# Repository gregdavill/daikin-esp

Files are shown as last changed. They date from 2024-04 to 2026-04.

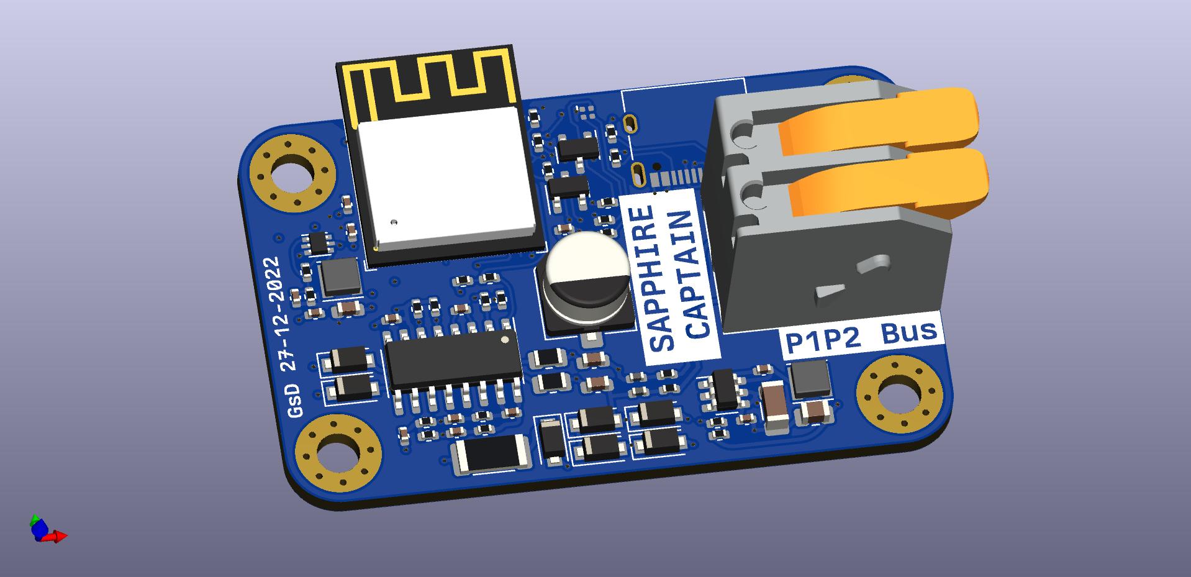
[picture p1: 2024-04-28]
pcb/sapphire-captain/sapphire-captain.jpg

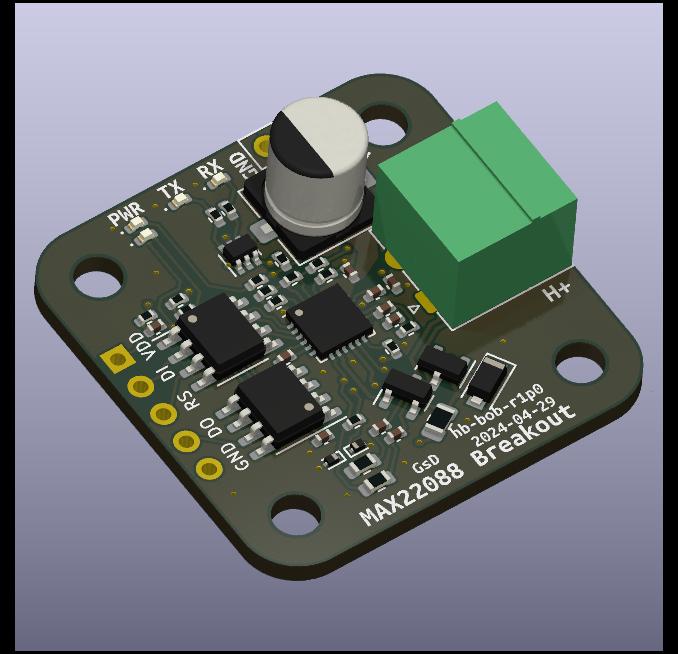
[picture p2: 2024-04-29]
pcb/hb-bob/hb-bob-r1p0.jpg

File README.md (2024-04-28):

# Daikin-ESP

Wireless A/C Controller, an ESP32-C3 based hardware module to connect to a Daikin ducted A/C system and enable WiFi control in Home Assistant.

## Hardware

The PCB repo contains a few different designs:
 - `saphire-captain` : Initial ESP32 + XL1192 board. Power extraction from the bus and transmission didn't work well.
 - `hb-bob-r0.1` : Breakout board designed for the MAX22088 homebus transceiver. This board enabled rx/tx and power from the P1P2 bus.
 - `esp-daikin-r1.0` : Basic ESP32-C3 board with DCDC, dosigned to attach directly to the hb-bob board.

## Firmware

The current firmware targets the `esp-daikin` + `hb-bob` PCB combo. Initial flashing is done with a serial connection to the ESP32-C3. Once flashed OTA updates are supported.
The firmware makes use of esphome to provide the WiFi and Home Assistant code base. A simple C++ component is used to handle the low level encoding, and protocol level decoding.

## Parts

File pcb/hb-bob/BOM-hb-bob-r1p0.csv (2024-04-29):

Comment | Designator | Footprint | LCSC
1K | R13 | R_0402_1005Metric | C11702
1R | R14 | R_0805_2012Metric | C131397
4.7R | R15,R16 | R_0603_1608Metric | C137705
5.6V | D7,D8 | D_SOD-923 | C151980
0.1uF | C1,C2,C3,C5,C8 | C_0402_1005Metric | C1525
10uF | C10,C11,C6 | C_0402_1005Metric | C15525
GREEN | D1,D2,D3,D5 | LED_0402_1005Metric | C165980
180k | R7 | R_0402_1005Metric | C25760
20K | R1,R10,R12,R17,R18,R2,R5,R6 | R_0402_1005Metric | C25765
27K | R8 | R_0402_1005Metric | C25771
4.3K | R9 | R_0402_1005Metric | C25899
82R | R11 | R_0402_1005Metric | C2909389
220uF | C4 | CP_Elec_6.3x7.7 | C2918361
74LVC2G14DW-7 | U3 | SOT-363_SC-70-6 | C362110
62k | R3 | R_0402_1005Metric | C37825
CA-IS3720 | U1,U2 | SOIC-8_3.9x4.9mm_P1.27mm | C428882
MAX22088 | U4 | QFN-24-1EP_4x4mm_P0.5mm_EP2.6x2.6mm | C5258925
1uF | C7,C9 | C_0402_1005Metric | C52923
0R | R4 | R_0402_1005Metric | C60485
Terminal Block 2P | J3 | PhoenixContact_MC_1,5_2-G-3.81_1x02_P3.81mm_Horizontal | C8387
24V | D6 | D_SOD-123F | C908212
BAT54S | D4,D9 | SOT-23 | C916425
PH_01x05 | J1 | PinHeader_1x05_P2.54mm_Vertical
PinHeader 1x02 | J2 | PinHeader_1x02_P2.54mm_Vertical

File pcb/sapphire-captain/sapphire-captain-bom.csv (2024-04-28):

Item | Qty | Reference(s) | Value | LibPart | Footprint | Datasheet | MFG | Mfg | PN | PN-alt0 | Tol | lcsc
21 | 7 | C2, C4, C13, C16, C18, C19, C20 | 0.1uF | Device:C | Capacitor_SMD:C_0402_1005Metric | ~ | Samsung Electro-Mechanics | Yageo | CL05B104KO5NNNC
3 | 1 | C3 | 22uF | Device:C | Capacitor_SMD:C_1206_3216Metric | ~ | Samsung Electro-Mechanics | Yageo | CL31A226KAHNNNE
9 | 3 | C5, C6, C11 | 10uF | Device:C | Capacitor_SMD:C_0603_1608Metric | ~ | Samsung Electro-Mechanics | Yageo | CL10A106KP8NNNC
9 | 3 | C7, C8, C9 | 22nF | Device:C | Capacitor_SMD:C_0402_1005Metric | ~ | Samsung Electro-Mechanics | Yageo | CL05B223KB5VPNC
3 | 1 | C10 | 6.8pF | Device:C | Capacitor_SMD:C_0402_1005Metric | ~ | Samsung Electro-Mechanics | Yageo | CC0402CRNPO9BN6R8
3 | 1 | C12 | 470p | Device:C | Capacitor_SMD:C_0402_1005Metric | ~ | Samsung Electro-Mechanics |  | CL05B471KB5NNNC
3 | 1 | C14 | 1uF | Device:C | Capacitor_SMD:C_0402_1005Metric | ~ | Samsung Electro-Mechanics | Yageo | CL05X105KA5NQNC
3 | 1 | C15 | 47uF | Device:C_Polarized_US | Capacitor_SMD:CP_Elec_6.3x4.5 | ~ | DMBJ |  | RVT1V470M0605 | ROQANG |  | C72522
3 | 1 | C17 | 22uF | Device:C | Capacitor_SMD:C_0805_2012Metric | ~ | Samsung Electro-Mechanics |  | CL21A226MAYNNNE
3 | 1 | D1 | 16V | Device:D_TVS_Filled | Diode_SMD:D_SOD-123F | ~ |  |  | BZT52H-C16,115
12 | 4 | D2, D3, D4, D5 | D_Filled | Device:D_Filled | Diode_SMD:D_SOD-123F | ~ | Shandong Jingdao Microelectronics |  | 1N5819W
6 | 2 | D6, D7 | 5.6V | Device:D_TVS_Filled | Diode_SMD:D_SOD-123F | ~ |  |  | BZT52H-B5V6,115
3 | 1 | D8 | LED_ARGB | Device:LED_ARGB | lib:0404LED_RGB | ~
6 | 2 | F1, F2 | 100mA | Device:Fuse_Small | Fuse:Fuse_0402_1005Metric | ~ | Shenzhen JDT Fuse |  | JFC0402-0250FS
6 | 2 | FB1, FB2 | 220R | Device:FerriteBead_Small | Inductor_SMD:L_0402_1005Metric | ~ | Chilisin Elec |  | PBY100505T-101Y-N
3 | 1 | J1 | Conn_01x02 | Connector_Generic:Conn_01x02 | TerminalBlock_WAGO:TerminalBlock_WAGO_236-102_1x02_P5.00mm_45Degree | ~ | WAGO Corporation |  | 2604-1102
3 | 1 | J2 | USB_C_Receptacle_USB2.0 | Connector:USB_C_Receptacle_USB2.0 | Connector_USB:USB_C_Receptacle_XKB_U262-16XN-4BVC11 | https://www.usb.org/sites/default/files/documents/usb_type-c.zip
3 | 1 | J3 | JTAG/SW Interface | Connector_Generic:Conn_02x05_Odd_Even | Connector_PinHeader_1.27mm:PinHeader_2x05_P1.27mm_Vertical_SMD | ~
3 | 1 | L1 | 2.2uH | Device:L_Small | Inductor_SMD:L_Taiyo-Yuden_NR-30xx | ~ |  | MINGSTAR | UT252010N-2R2M
3 | 1 | L2 | 10uH | Device:L_Small | Inductor_SMD:L_Taiyo-Yuden_NR-30xx | ~ | YJYCOIN |  | YNR3015-100M |  |  | C340363
6 | 2 | Q1, Q2 | 2N7002 | Device:Q_NMOS_GSD | Package_TO_SOT_SMD:SOT-23 | ~ | Jiangsu Changjing Electronics Technology Co., Ltd. |  | 2N7002
3 | 1 | R1 | 30R | Device:R | Resistor_SMD:R_2010_5025Metric | ~ | YAGEO |  | RC2010JK-0730RL
6 | 2 | R2, R3 | 1.5k | Device:R | Resistor_SMD:R_0402_1005Metric | ~ | YAGEO |  | RC0402FR-071K5L
6 | 2 | R4, R17 | 22k | Device:R | Resistor_SMD:R_0402_1005Metric | ~ | YAGEO | Yageo | RC0402FR-0722KL
3 | 1 | R5 | 115k | Device:R | Resistor_SMD:R_0402_1005Metric | ~ | YAGEO | Yageo | RC0402FR-07115KL |  | 1%
3 | 1 | R6 | 25.5k | Device:R | Resistor_SMD:R_0402_1005Metric | ~ | YAGEO | Yageo | RC0402FR-0725K5L
3 | 1 | R7 | 100k | Device:R | Resistor_SMD:R_0402_1005Metric | ~ | YAGEO | Yageo | RC0402FR-07100KL |  | 1%
6 | 2 | R8, R9 | 75k | Device:R | Resistor_SMD:R_0402_1005Metric | ~ | YAGEO |  | RC0402FR-0775KL
6 | 2 | R10, R11 | 1R | Device:R | Resistor_SMD:R_0805_2012Metric | ~ | YAGEO |  | RC0805FR-071RL
3 | 1 | R12 | DNP | Device:R | Resistor_SMD:R_0402_1005Metric | ~ | YAGEO
3 | 1 | R13 | 0R | Device:R | Resistor_SMD:R_0402_1005Metric | ~ | YAGEO |  | RC0402FR-070RL
15 | 5 | R14, R15, R16, R18, R21 | 10k | Device:R | Resistor_SMD:R_0402_1005Metric | ~ | YAGEO |  | RC0402FR-0710KL
3 | 1 | R19 | 4.7k | Device:R | Resistor_SMD:R_0402_1005Metric | ~ | YAGEO |  | RC0402FR-074K7L
9 | 3 | R20, R22, R23 | 470R | Device:R | Resistor_SMD:R_0402_1005Metric | ~ | YAGEO |  | RC0402FR-07470RL
6 | 2 | R24, R25 | 5.1K | Device:R | Resistor_SMD:R_0402_1005Metric | ~ | YAGEO |  | RC0402FR-075K1L
3 | 1 | SW1 | SW_DIP_x01 | Switch:SW_DIP_x01 | Button_Switch_SMD:SW_SPST_PTS810 | ~ | C&K |  | PTS810SJK250SMTRLFS
3 | 1 | U1 | MT2492 | lib:MT2492 | Package_TO_SOT_SMD:SOT-23-6 | https://datasheet.lcsc.com/lcsc/1810262207_XI-AN-Aerosemi-Tech-MT2492_C89358.pdf | XI'AN Aerosemi Tech |  | MT2492
3 | 1 | U2 | TLV62569DRL | Regulator_Switching:TLV62569DRL | Package_TO_SOT_SMD:SOT-666 | http://www.ti.com/lit/ds/symlink/tlv62569.pdf | Texas Instruments | Texas Instruments | TLV62569DRLR
3 | 1 | U3 | XL1192 | sapphire-captain:XL1192 | Package_SO:SO-16_3.9x9.9mm_P1.27mm |  | XLSEMI |  | XL1192S
3 | 1 | U4 | ESP32-C3-MINI-1 | Espressif:ESP32-C3-MINI-1 | Espressif:ESP32-C3-MINI-1 | https://www.espressif.com/sites/default/files/documentation/esp32-c3-mini-1_datasheet_en.pdf

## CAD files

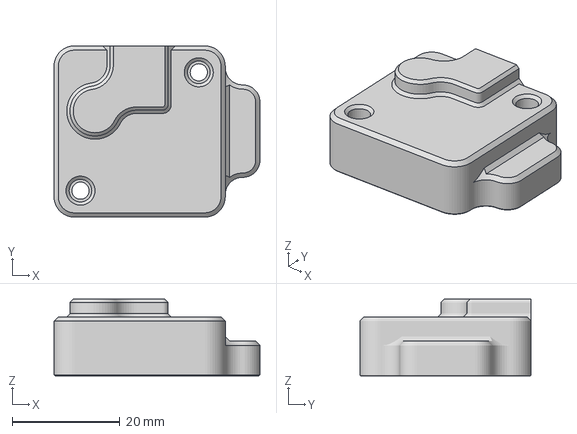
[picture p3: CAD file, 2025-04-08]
mech/top_1.0.0.3mf
38.3 x 31.9 x 14.3 mm

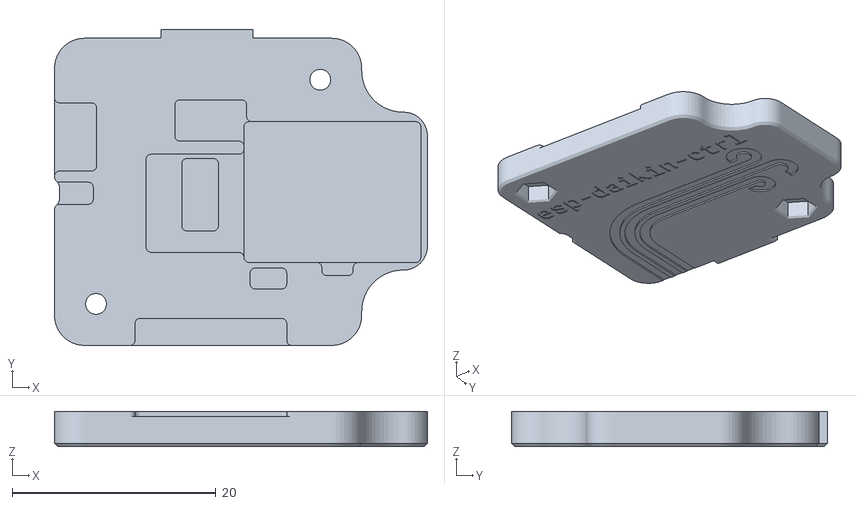
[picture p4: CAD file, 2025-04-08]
mech/bot_1.1.0.stl
36.6 x 31.0 x 3.44

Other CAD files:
mech/top_1.1.0.stl
mech/bot_1.0.0.3mf

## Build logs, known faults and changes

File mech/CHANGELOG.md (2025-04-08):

# Change Log
Mechanical designs are developed in Autodesk Fusion. Exports of that design are used for 3d prints and saved in this repo.

## [1.1.0]
2025-02-13: Updated design. Printed with SLS Nylon.

### Fixes
 - Shrink hole sizes to better support fasteners

### Files
 - top_1.1.0.stl
 - bot_1.1.0.stl

## [1.0.0]
2024-03-08: Initial design. Printed with SLS Nylon.

### Files
 - top_1.0.0.3mf
 - bot_1.0.0.3mf

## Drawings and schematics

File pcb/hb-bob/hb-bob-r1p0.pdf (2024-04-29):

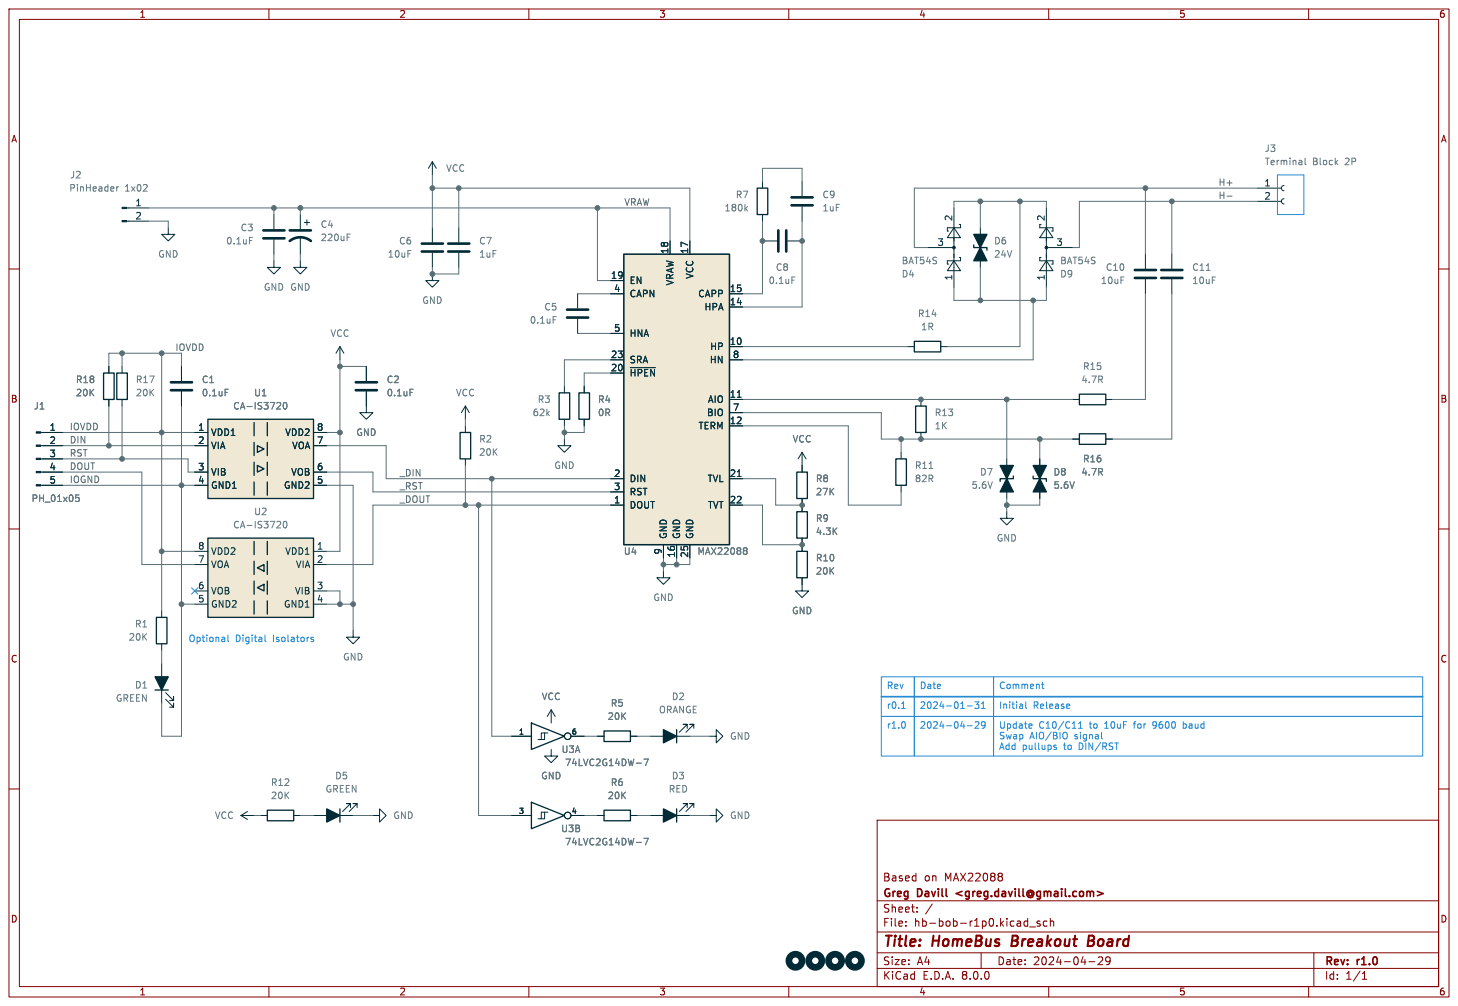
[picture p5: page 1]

9 U1 CA-IS3720 VDD1 1 VIA 2 VIB 3 GND1 4 GND2 5 VOB 6 VOA 7 VDD2 8 C1

Id: 1/1 Title: HomeBus Breakout Board

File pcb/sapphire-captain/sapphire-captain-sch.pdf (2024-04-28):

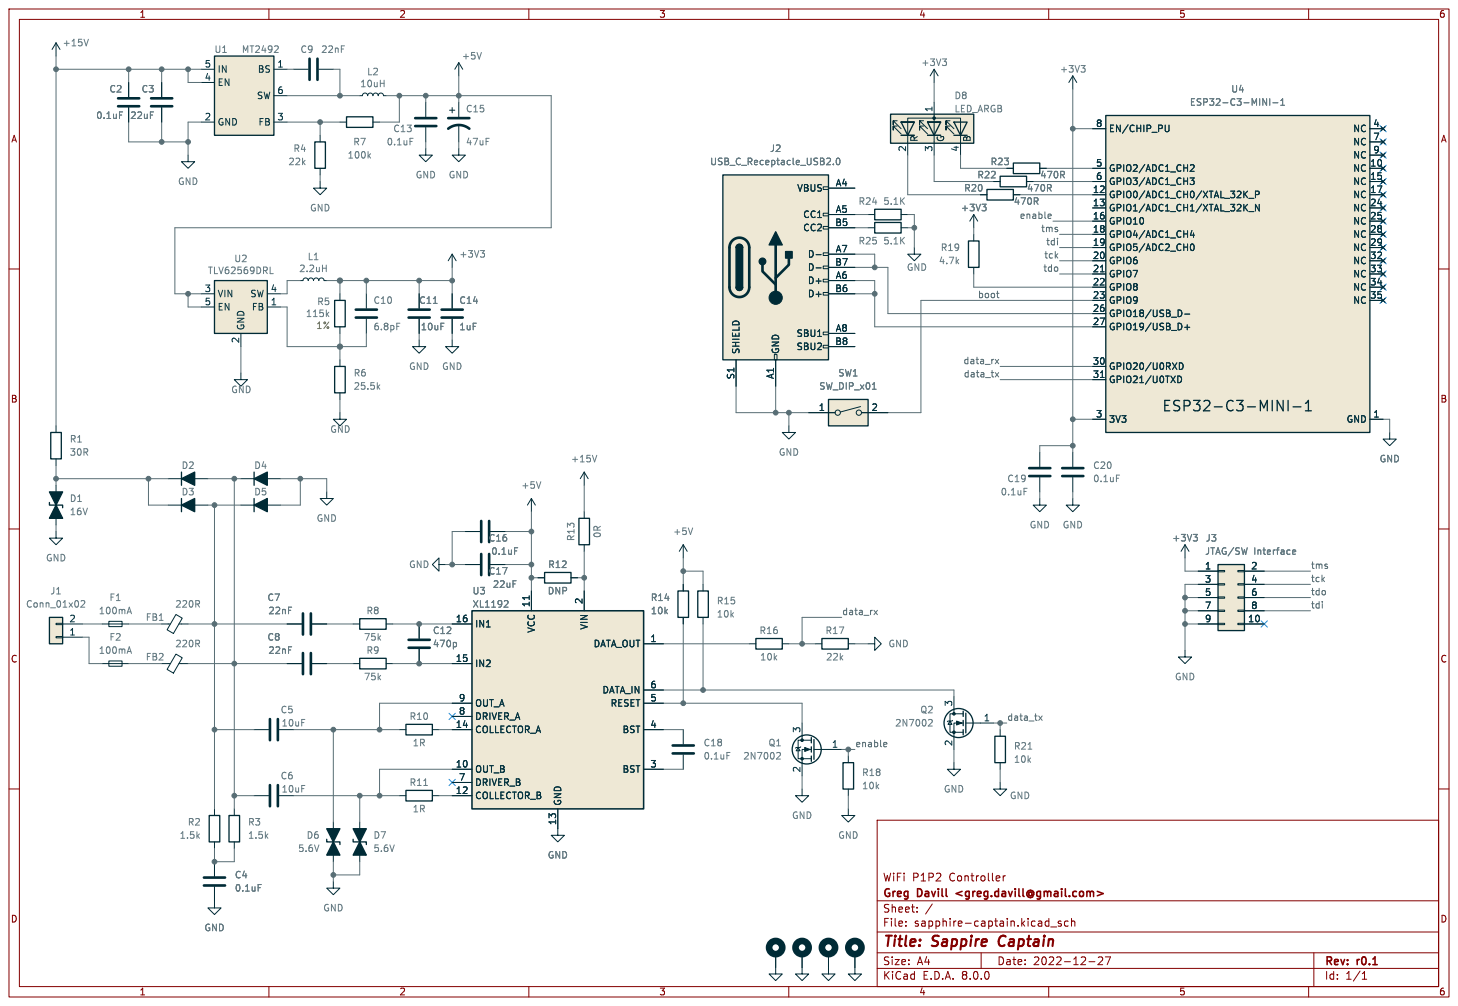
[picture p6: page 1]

2 BST 3 BST 4 RESET 5 DATA_IN 6 DRIVER_B 7 DRIVER_A 8 OUT_A 9 GND

Id: 1/1 Title: Sappire Captain

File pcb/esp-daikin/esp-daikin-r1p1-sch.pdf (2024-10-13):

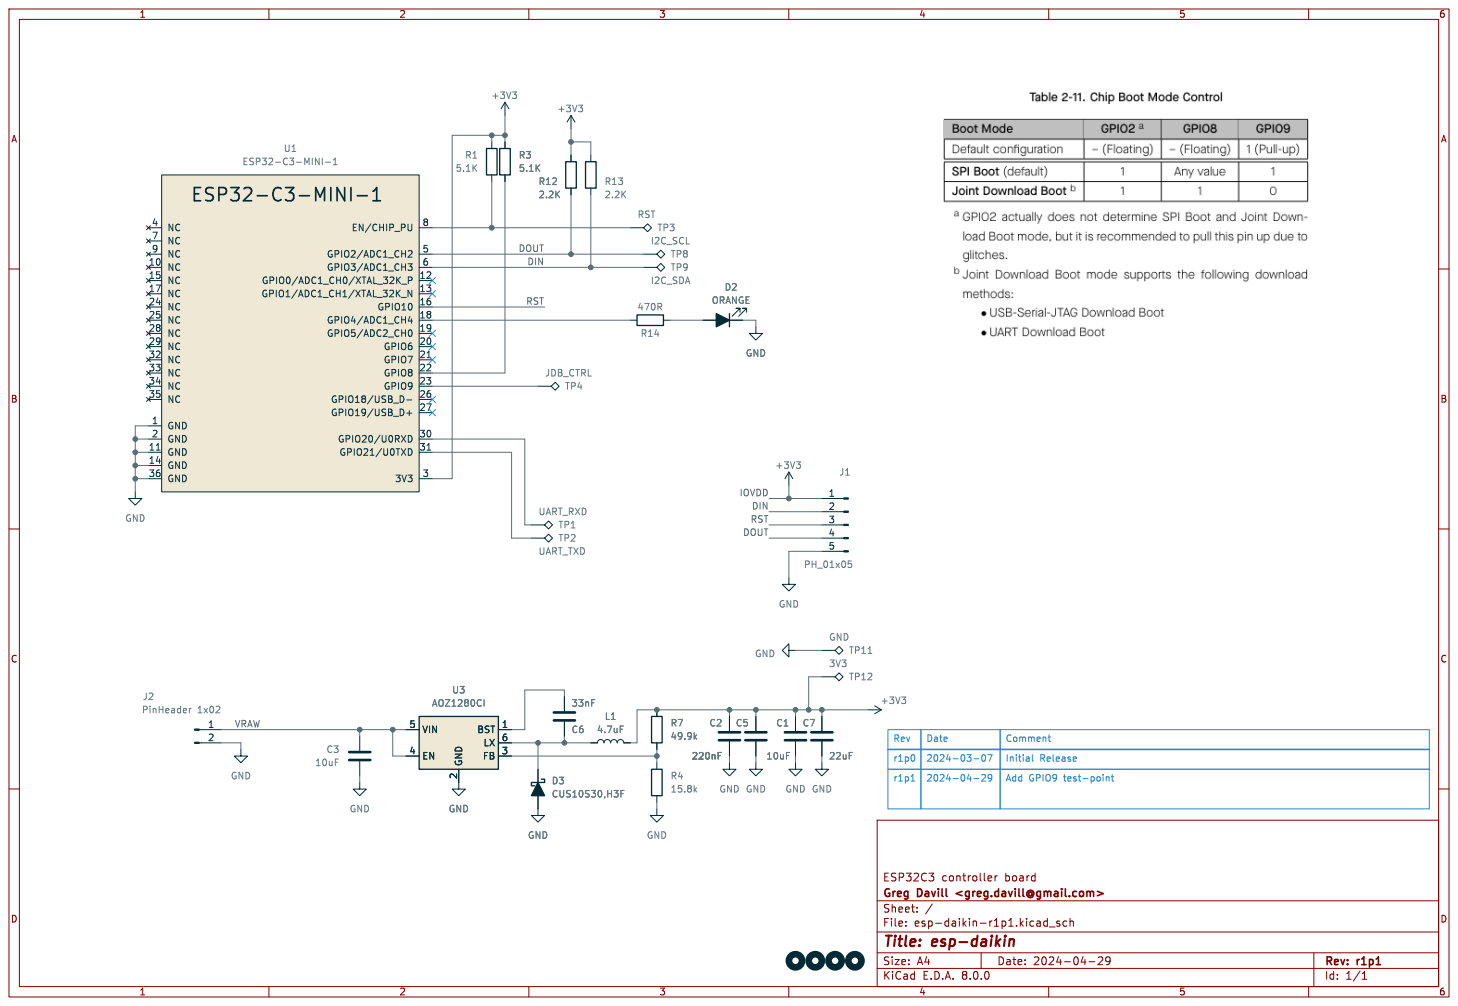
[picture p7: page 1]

Id: 1/1 Title: esp-daikin

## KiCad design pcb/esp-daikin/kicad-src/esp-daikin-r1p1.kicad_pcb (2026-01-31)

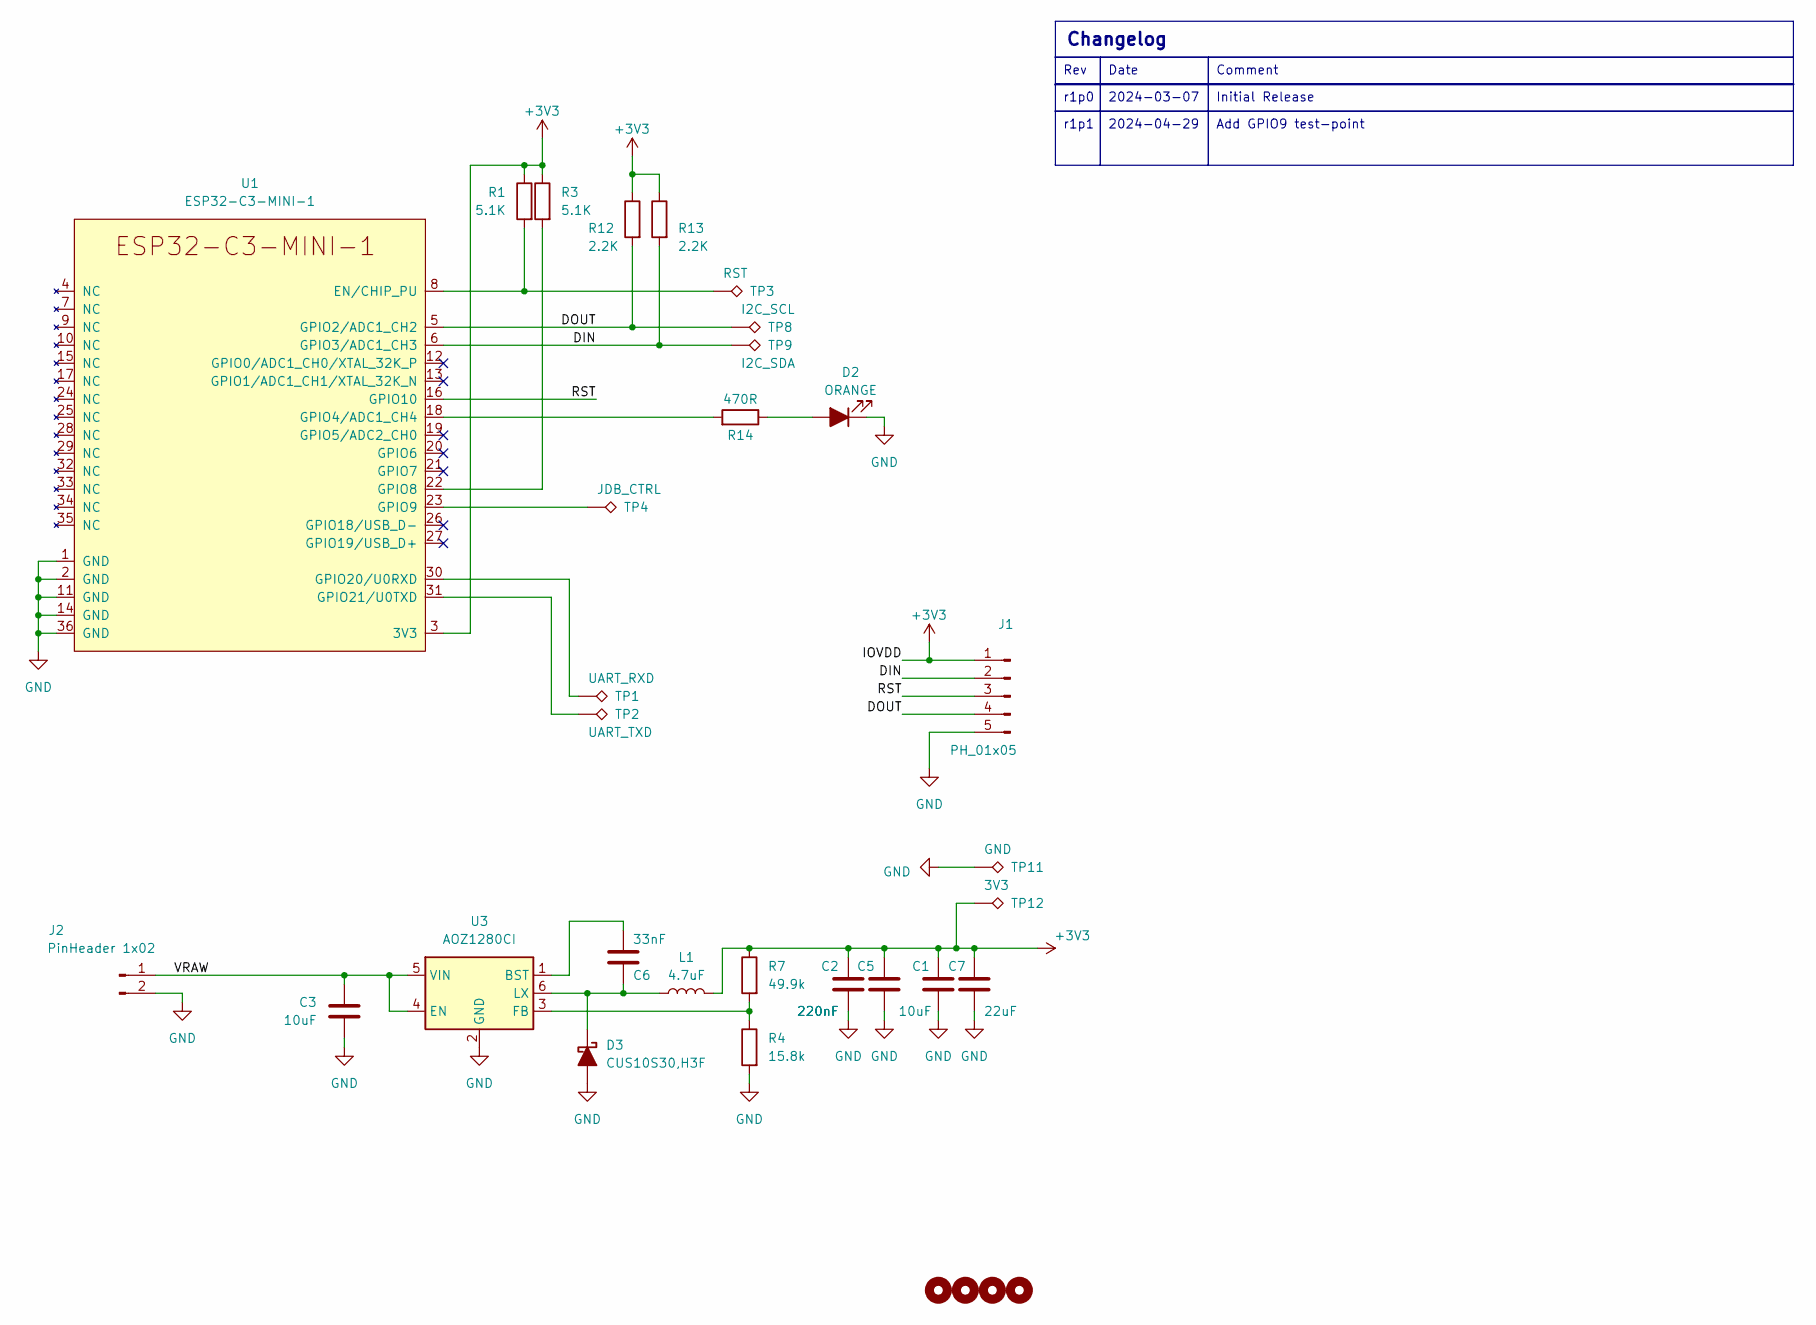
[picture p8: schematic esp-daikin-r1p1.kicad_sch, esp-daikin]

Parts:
C1, C3: 10uF; C_0603_1608Metric; LCSC C96446
C2, C5: 220nF; C_0402_1005Metric; LCSC C16772
C6: 33nF; C_0402_1005Metric; LCSC C106862
C7: 22uF; C_0603_1608Metric; LCSC C59461
D2: ORANGE; LED_0402_1005Metric; LCSC C965791
D3: CUS10S30,H3F; D_SOD-523; LCSC C8523
H1, H2, H3, H4: MountingHole; MountingHole_3.2mm_M3_DIN965
J1: PH_01x05; PinHeader_1x05_P2.54mm_Vertical
J2: PinHeader 1x02; PinHeader_1x02_P2.54mm_Vertical
L1: 4.7uF; L_0805_2012Metric; LCSC C63166
R1, R3: 5.1K; R_0402_1005Metric; LCSC C25905
R4: 15.8k; R_0402_1005Metric; LCSC C26956
R7: 49.9k; R_0402_1005Metric; LCSC C25897
R12, R13: 2.2K; R_0402_1005Metric; LCSC C25879
R14: 470R; R_0402_1005Metric; LCSC C25117
TP1: UART_RXD; TestPoint_Pad_D1.0mm
TP2: UART_TXD; TestPoint_Pad_D1.0mm
TP3: RST; TestPoint_Pad_D1.0mm
TP4: JDB_CTRL; TestPoint_Pad_D1.0mm
TP8: I2C_SCL; TestPoint_Pad_D1.0mm
TP9: I2C_SDA; TestPoint_Pad_D1.0mm
TP11: GND; TestPoint_Pad_D1.0mm
TP12: 3V3; TestPoint_Pad_D1.0mm
U1: ESP32-C3-MINI-1; LCSC C2934569
U3: AOZ1280CI; SOT-23-6; LCSC C41240

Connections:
+3V3: C1.1, C2.1, C5.1, C7.1, J1.1, L1.2, R1.1, R3.1, R7.1, R12.1, R13.1, TP12.1, U1.3 (3V3)
/DIN: J1.2, R13.2, TP9.1, U1.6 (GPIO3/ADC1_CH3)
/DOUT: J1.4, R12.2, TP8.1, U1.5 (GPIO2/ADC1_CH2)
/RST: J1.3, U1.16 (GPIO10)
/VRAW: C3.1, J2.1, U3.4 (EN), U3.5 (VIN)
GND: C1.2, C2.2, C3.2, C5.2, C7.2, D2.1 (K), D3.2 (A), J1.5, J2.2, R4.2, TP11.1, U1.1 (GND), U1.2 (GND), U1.11 (GND), U1.14 (GND), U1.36 (GND), U1.37 (GND), U1.38 (GND), U1.39 (GND), U1.40 (GND), U1.41 (GND), U1.42 (GND), U1.43 (GND), U1.44 (GND), U1.45 (GND), U1.46 (GND), U1.47 (GND), U1.48 (GND), U1.49 (GND), U1.50 (GND), U1.51 (GND), U1.52 (GND), U1.53 (GND), U3.2 (GND)
unnamed: D2.2 (A), R14.1
unnamed: C6.1, D3.1 (K), L1.1, U3.6 (LX)
unnamed: R1.2, TP3.1, U1.8 (EN/CHIP_PU)
unnamed: R14.2, U1.18 (GPIO4/ADC1_CH4)
unnamed: R3.2, U1.22 (GPIO8)
unnamed: TP4.1, U1.23 (GPIO9)
unnamed: TP1.1, U1.30 (GPIO20/U0RXD)
unnamed: TP2.1, U1.31 (GPIO21/U0TXD)
unnamed: C6.2, U3.1 (BST)
unnamed: R4.1, R7.2, U3.3 (FB)

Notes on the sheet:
Add GPIO9 test-point
Date
r1p0
Changelog
Rev
Comment
2024-03-07
2024-04-29
Initial Release
r1p1

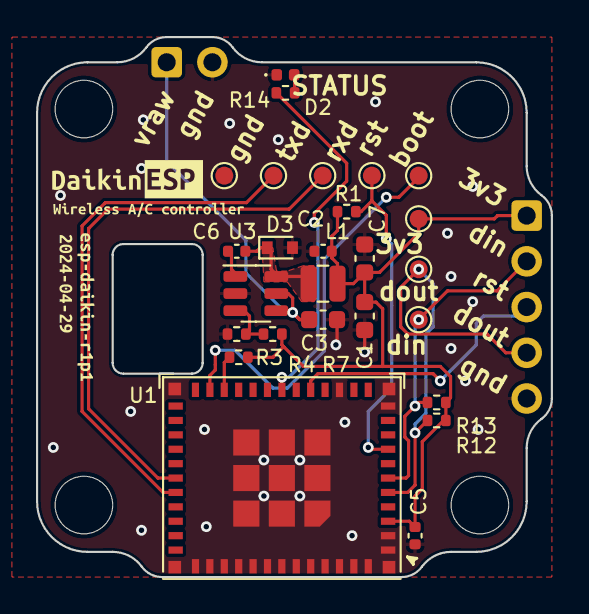
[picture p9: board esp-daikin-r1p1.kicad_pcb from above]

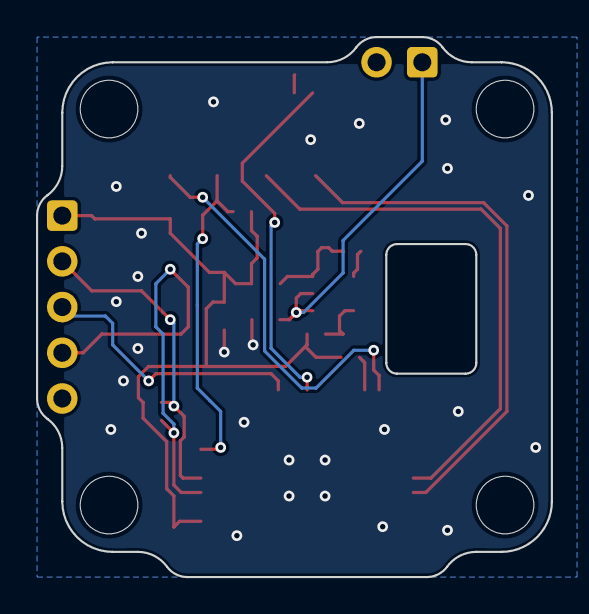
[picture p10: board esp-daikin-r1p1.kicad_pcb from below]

Board: 2 copper layers, 28.6 x 30.0 mm, 37 parts (6 on the bottom side), 16 nets.

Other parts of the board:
kibuzzard-65E1B0DF: G***; kibuzzard-65E1B0DF
kibuzzard-65E1B071: G***; kibuzzard-65E1B071
kibuzzard-65E1B080: G***; kibuzzard-65E1B080
kibuzzard-663027A7: G***; kibuzzard-663027A7
kibuzzard-663027CC: G***; kibuzzard-663027CC

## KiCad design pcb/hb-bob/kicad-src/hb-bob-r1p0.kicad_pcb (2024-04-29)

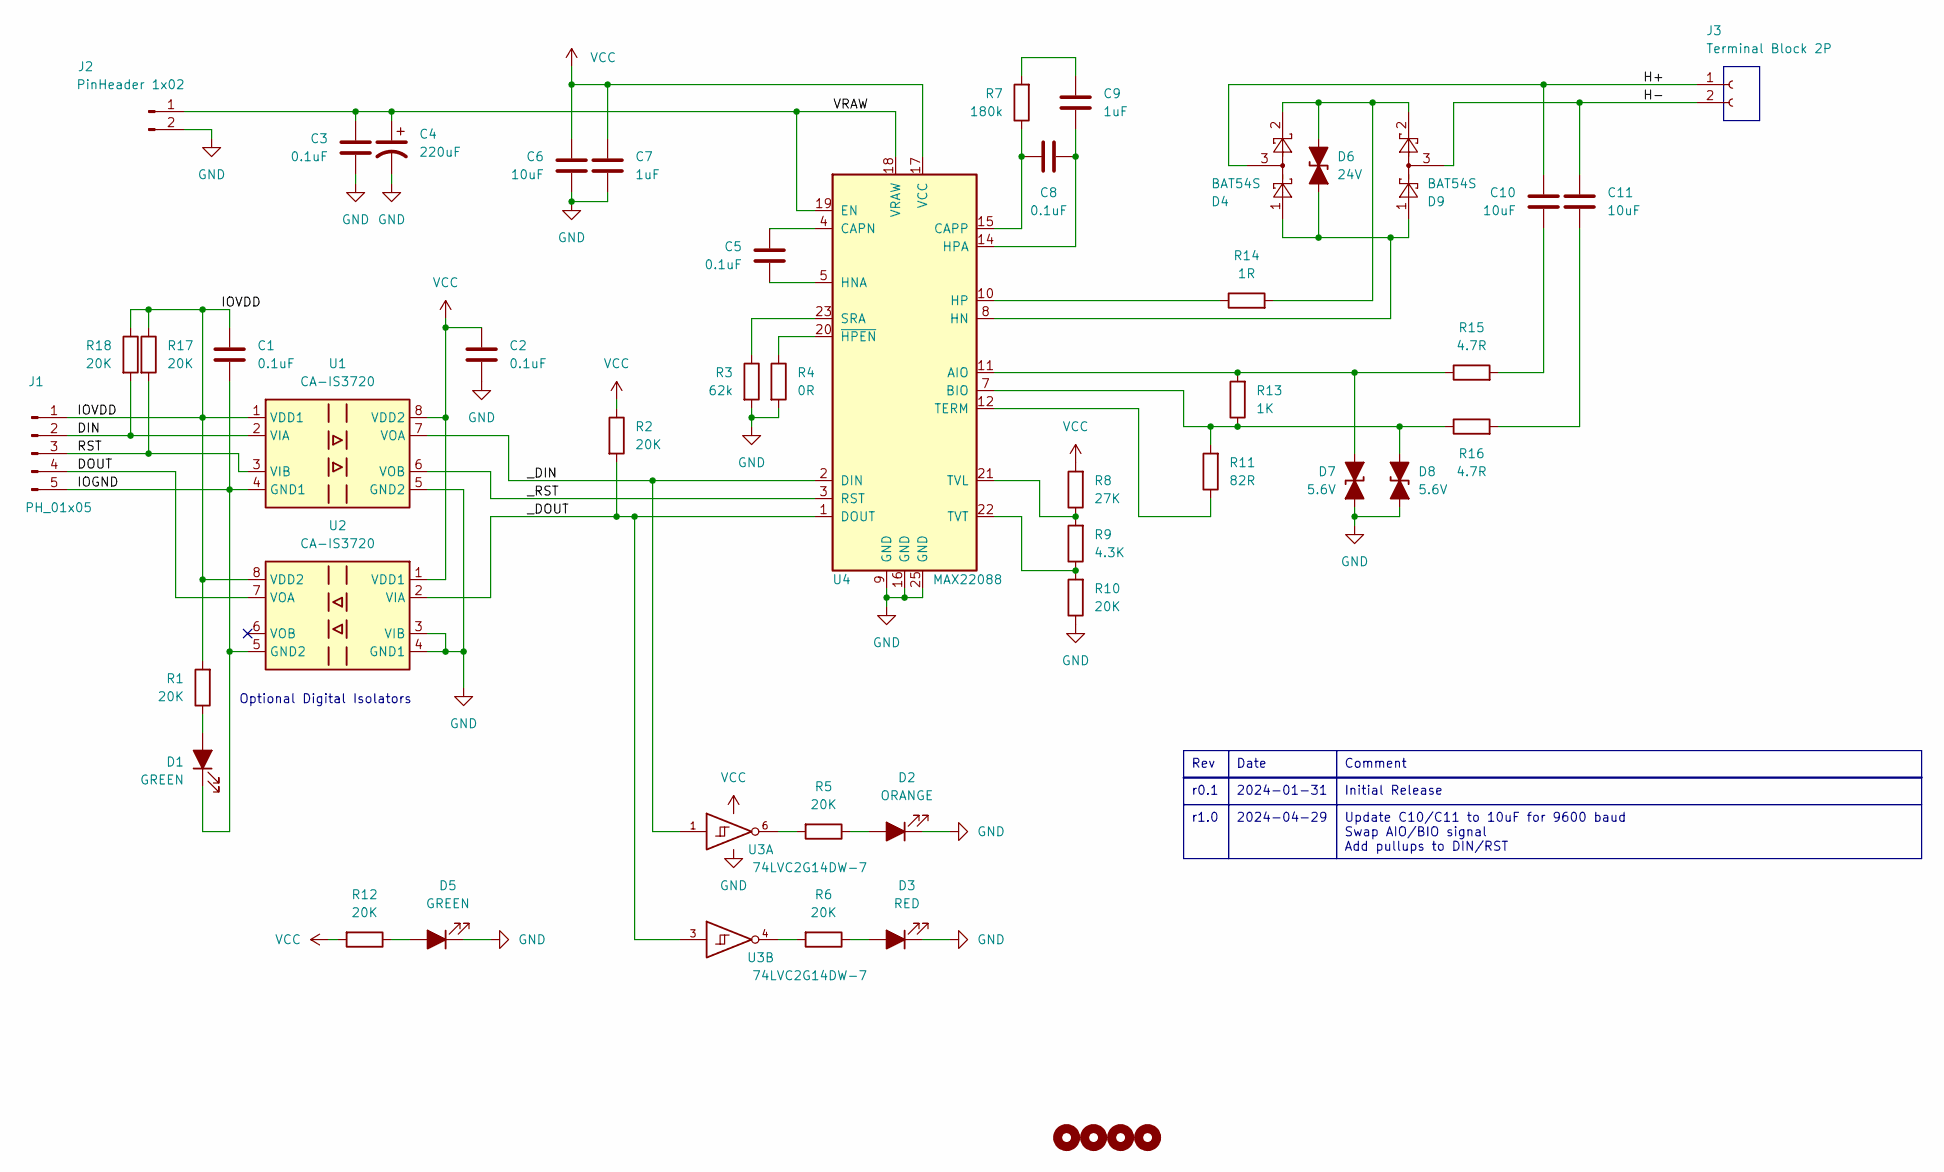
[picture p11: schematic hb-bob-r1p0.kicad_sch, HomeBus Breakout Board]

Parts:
C1, C2, C3, C5, C8: 0.1uF; C_0402_1005Metric; LCSC C1525
C4: 220uF; CP_Elec_6.3x7.7; LCSC C2918361
C6, C10, C11: 10uF; C_0402_1005Metric; LCSC C15525
C7, C9: 1uF; C_0402_1005Metric; LCSC C52923
D1, D5: GREEN; LED_0402_1005Metric; LCSC C165980
D2: ORANGE; LED_0402_1005Metric; LCSC C165980
D3: RED; LED_0402_1005Metric; LCSC C165980
D4, D9: BAT54S; SOT-23; LCSC C916425
D6: 24V; D_SOD-123F; LCSC C908212
D7, D8: 5.6V; D_SOD-923; LCSC C151980
H1, H2, H3, H4: MountingHole; MountingHole_3.2mm_M3_DIN965
J1: PH_01x05; PinHeader_1x05_P2.54mm_Vertical
J2: PinHeader 1x02; PinHeader_1x02_P2.54mm_Vertical
J3: Terminal Block 2P; PhoenixContact_MC_1,5_2-G-3.81_1x02_P3.81mm_Horizontal; LCSC C8387
R1, R2, R5, R6, R10, R12, R17, R18: 20K; R_0402_1005Metric; LCSC C25765
R3: 62k; R_0402_1005Metric; LCSC C37825
R4: 0R; R_0402_1005Metric; LCSC C60485
R7: 180k; R_0402_1005Metric; LCSC C25760
R8: 27K; R_0402_1005Metric; LCSC C25771
R9: 4.3K; R_0402_1005Metric; LCSC C25899
R11: 82R; R_0402_1005Metric; LCSC C2909389
R13: 1K; R_0402_1005Metric; LCSC C11702
R14: 1R; R_0805_2012Metric; LCSC C131397
R15, R16: 4.7R; R_0603_1608Metric; LCSC C137705
U1, U2: CA-IS3720; SOIC-8_3.9x4.9mm_P1.27mm; LCSC C428882
U3: 74LVC2G14DW-7; SOT-363_SC-70-6; LCSC C362110
U4: MAX22088; QFN-24-1EP_4x4mm_P0.5mm_EP2.6x2.6mm; LCSC C5258925

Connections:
/DIN: J1.2, R18.2, U1.2 (VIA)
/DOUT: J1.4, U2.7 (VOA)
/H+: C10.2, D4.3, J3.1
/H-: C11.2, D9.3, J3.2
/IOGND: C1.2, D1.1 (K), J1.5, U1.4 (GND1), U2.5 (GND2)
/IOVDD: C1.1, J1.1, R1.2, R17.1, R18.1, U1.1 (VDD1), U2.8 (VDD2)
/RST: J1.3, R17.2, U1.3 (VIB)
/VRAW: C3.1, C4.1, J2.1, U4.18 (VRAW), U4.19 (EN)
/_DIN: U1.7 (VOA), U3.1, U4.2 (DIN)
/_DOUT: R2.2, U2.2 (VIA), U3.3, U4.1 (DOUT)
/_RST: U1.6 (VOB), U4.3 (RST)
GND: C2.2, C3.2, C4.2, C6.2, C7.2, D2.1 (K), D3.1 (K), D5.1 (K), D7.2 (A2), D8.2 (A2), J2.2, R3.2, R4.2, R10.1, U1.5 (GND2), U2.3 (VIB), U2.4 (GND1), U3.2 (GND), U4.9 (GND), U4.16 (GND), U4.25 (GND)
unnamed: C9.1, R7.2
unnamed: C10.1, R15.2
unnamed: C11.1, R16.2
unnamed: D1.2 (A), R1.1
unnamed: D2.2 (A), R5.1
unnamed: D3.2 (A), R6.1
unnamed: D5.2 (A), R12.1
unnamed: D4.1, D6.1 (A1), D9.1, U4.8 (HN)
unnamed: D4.2, D6.2 (A2), D9.2, R14.2
unnamed: D7.1 (A1), R13.2, R15.1, U4.11 (AIO)
unnamed: D8.1 (A1), R11.2, R13.1, R16.1, U4.7 (BIO)
unnamed: R5.2, U3.6
unnamed: R6.2, U3.4
unnamed: C5.1, U4.4 (CAPN)
unnamed: C8.2, R7.1, U4.15 (CAPP)
unnamed: C5.2, U4.5 (HNA)
unnamed: R14.1, U4.10 (HP)
unnamed: C8.1, C9.2, U4.14 (HPA)
unnamed: R3.1, U4.23 (SRA)
unnamed: R11.1, U4.12 (TERM)
unnamed: R8.1, R9.2, U4.21 (TVL)
unnamed: R9.1, R10.2, U4.22 (TVT)
unnamed: R4.1, U4.20 (~HPEN)
VCC: C2.1, C6.1, C7.1, R2.1, R8.2, R12.2, U1.8 (VDD2), U2.1 (VDD1), U3.5 (VCC), U4.17 (VCC)

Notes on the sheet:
r0.1
2024-04-29
Initial Release
Update C10/C11 to 10uF for 9600 baud Swap AIO/BIO signal Add pullups to DIN/RST
Comment
Rev
2024-01-31
Date
r1.0
Optional Digital Isolators

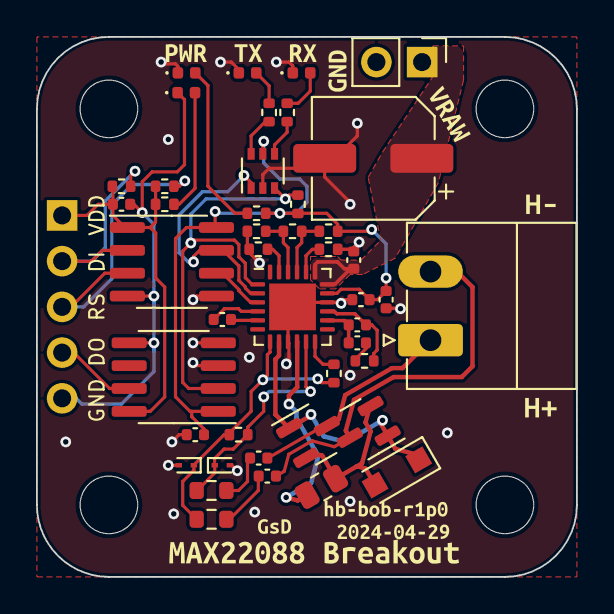
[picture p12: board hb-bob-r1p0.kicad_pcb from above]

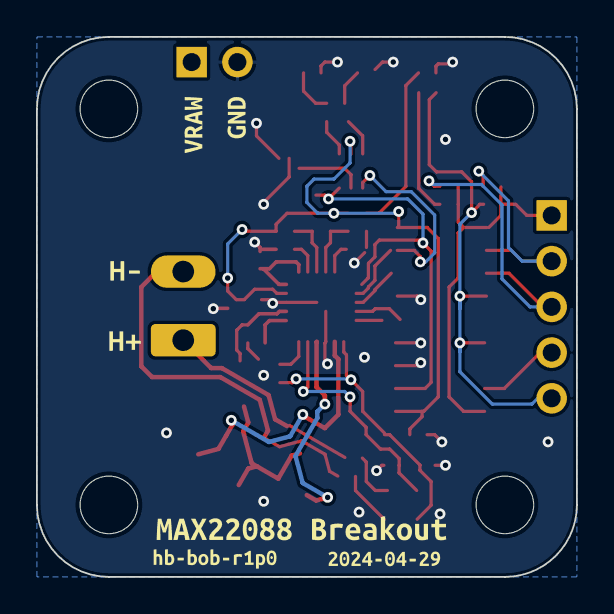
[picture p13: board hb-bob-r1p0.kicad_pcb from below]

Board: 2 copper layers, 30.0 x 30.0 mm, 67 parts (7 on the bottom side), 36 nets.

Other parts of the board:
kibuzzard-65B6C60D, kibuzzard-65B6C60D#2: G***; kibuzzard-65B6C60D
kibuzzard-65B6C61A, kibuzzard-65B6C61A#2: G***; kibuzzard-65B6C61A
kibuzzard-65B9E354: G***; kibuzzard-65B9E354
kibuzzard-65B62A1A, kibuzzard-65B62A1A#2: G***; kibuzzard-65B62A1A
kibuzzard-65B62B19, kibuzzard-65B62B19#2: G***; kibuzzard-65B62B19
kibuzzard-65B62B21, kibuzzard-65B62B21#2: G***; kibuzzard-65B62B21
kibuzzard-65B629C5: G***; kibuzzard-65B629C5
kibuzzard-65B629E6: G***; kibuzzard-65B629E6
kibuzzard-65B629EE: G***; kibuzzard-65B629EE
kibuzzard-662F7DF1: G***; kibuzzard-662F7DF1
kibuzzard-662F7DF9: G***; kibuzzard-662F7DF9
kibuzzard-662F7E09: G***; kibuzzard-662F7E09
kibuzzard-662F7E13: G***; kibuzzard-662F7E13

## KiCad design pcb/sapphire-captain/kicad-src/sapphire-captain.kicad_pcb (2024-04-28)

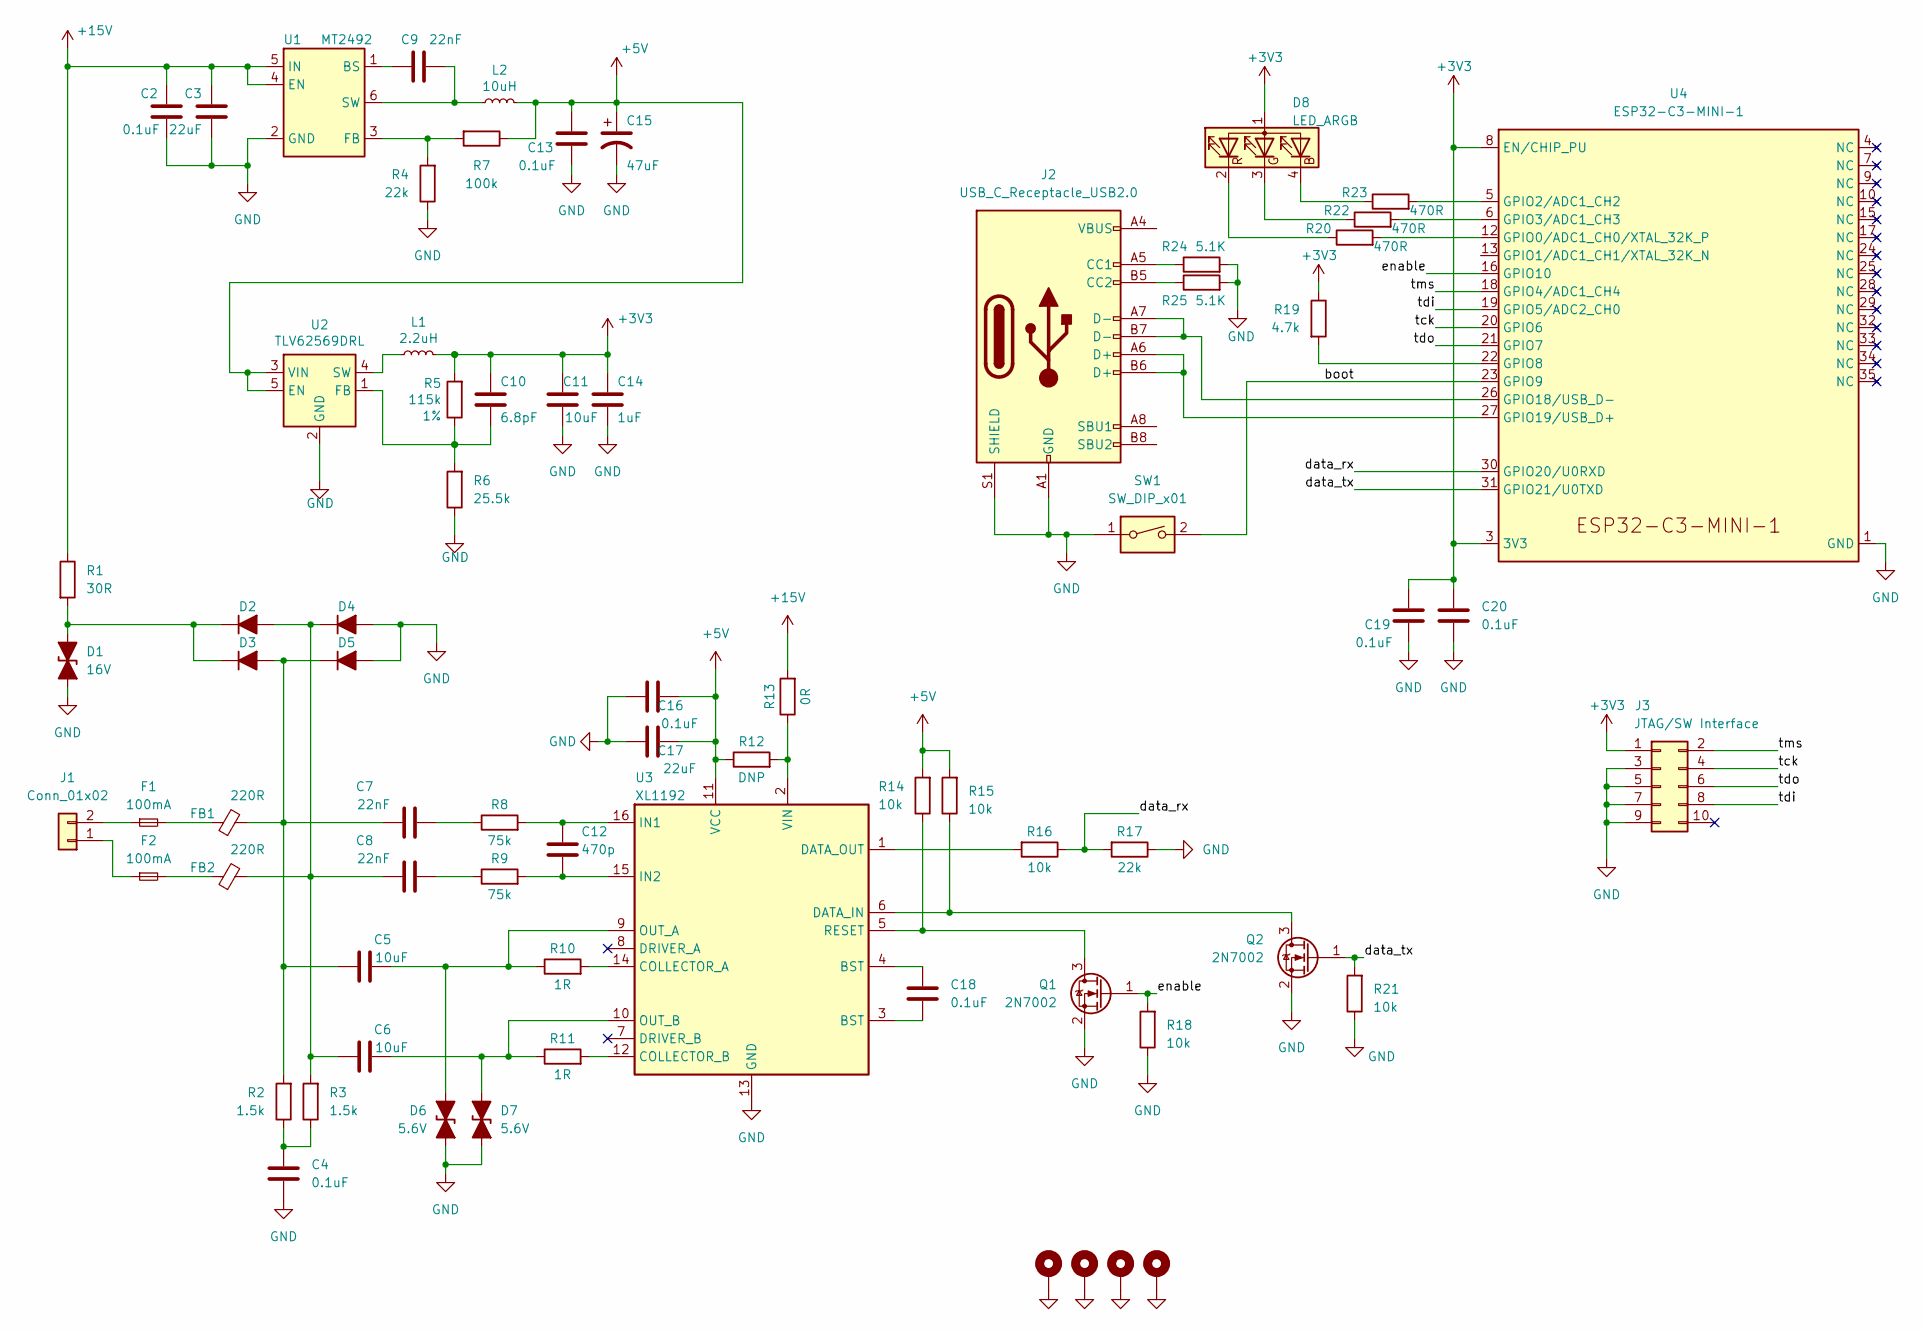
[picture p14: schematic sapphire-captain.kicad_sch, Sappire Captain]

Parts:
C2, C4, C13, C16, C18, C19, C20: 0.1uF; C_0402_1005Metric
C3: 22uF; C_1206_3216Metric
C5, C6, C11: 10uF; C_0603_1608Metric
C7, C8, C9: 22nF; C_0402_1005Metric
C10: 6.8pF; C_0402_1005Metric
C12: 470p; C_0402_1005Metric
C14: 1uF; C_0402_1005Metric
C15: 47uF; CP_Elec_6.3x4.5; lcsc C72522
C17: 22uF; C_0805_2012Metric
D1: 16V; D_SOD-123F
D2, D3, D4, D5: D_Filled; D_SOD-123F
D6, D7: 5.6V; D_SOD-123F
D8: LED_ARGB; 0404LED_RGB
F1, F2: 100mA; Fuse_0402_1005Metric
FB1, FB2: 220R; L_0402_1005Metric
H1, H2, H3, H4: MountingHole_Pad; MountingHole_3.2mm_M3_Pad_Via
J1: Conn_01x02; TerminalBlock_WAGO_236-102_1x02_P5.00mm_45Degree
J2: USB_C_Receptacle_USB2.0; USB_C_Receptacle_XKB_U262-16XN-4BVC11
J3: JTAG/SW Interface; PinHeader_2x05_P1.27mm_Vertical_SMD
L1: 2.2uH; L_Taiyo-Yuden_NR-30xx
L2: 10uH; L_Taiyo-Yuden_NR-30xx; lcsc C340363
Q1, Q2: 2N7002; SOT-23
R1: 30R; R_2010_5025Metric
R2, R3: 1.5k; R_0402_1005Metric
R4, R17: 22k; R_0402_1005Metric
R5: 115k; R_0402_1005Metric
R6: 25.5k; R_0402_1005Metric
R7: 100k; R_0402_1005Metric
R8, R9: 75k; R_0402_1005Metric
R10, R11: 1R; R_0805_2012Metric
R12: DNP; R_0402_1005Metric
R13: 0R; R_0402_1005Metric
R14, R15, R16, R18, R21: 10k; R_0402_1005Metric
R19: 4.7k; R_0402_1005Metric
R20, R22, R23: 470R; R_0402_1005Metric
R24, R25: 5.1K; R_0402_1005Metric
SW1: SW_DIP_x01; SW_SPST_PTS810
U1: MT2492; SOT-23-6
U2: TLV62569DRL; SOT-666
U3: XL1192; SO-16_3.9x9.9mm_P1.27mm
U4: ESP32-C3-MINI-1

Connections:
+3V3: C10.1, C11.1, C14.1, C19.1, C20.1, D8.1 (A), J3.1, L1.2, R5.2, R19.1, U4.3 (3V3), U4.8 (EN/CHIP_PU)
+5V: C13.1, C15.1, C16.2, C17.2, L2.2, R7.1, R12.1, R14.2, R15.2, U2.3 (VIN), U2.5 (EN), U3.11 (VCC)
+15V: C2.1, C3.1, R1.1, R13.2, U1.4 (EN), U1.5 (IN)
/boot: SW1.2, U4.23 (GPIO9)
/data_rx: R16.1, R17.2, U4.30 (GPIO20/U0RXD)
/data_tx: Q2.1 (G), R21.2, U4.31 (GPIO21/U0TXD)
/enable: Q1.1 (G), R18.2, U4.16 (GPIO10)
/tck: J3.4, U4.20 (GPIO6)
/tdi: J3.8, U4.19 (GPIO5/ADC2_CH0)
/tdo: J3.6, U4.21 (GPIO7)
/tms: J3.2, U4.18 (GPIO4/ADC1_CH4)
GND: C2.2, C3.2, C4.1, C11.2, C13.2, C14.2, C15.2, C16.1, C17.1, C19.2, C20.2, D1.2 (A2), D4.2 (A), D5.2 (A), D6.1 (A1), D7.1 (A1), H1.1, H2.1, H3.1, H4.1, J2.A1 (GND), J2.A12 (GND), J2.B1 (GND), J2.B12 (GND), J2.S1 (SHIELD), J3.3, J3.5, J3.7, J3.9, Q1.2 (S), Q2.2 (S), R4.1, R6.1, R17.1, R18.1, R21.1, R24.2, R25.2, SW1.1, U1.2 (GND), U2.2 (GND), U3.13 (GND), U4.1 (GND), U4.2 (GND), U4.36 (GND), U4.37 (GND), U4.38 (GND), U4.39 (GND), U4.40 (GND), U4.41 (GND), U4.42 (GND), U4.43 (GND), U4.44 (GND), U4.45 (GND), U4.46 (GND), U4.47 (GND), U4.48 (GND), U4.49 (GND), U4.50 (GND), U4.51 (GND), U4.52 (GND), U4.53 (GND)
unnamed: C4.2, R2.1, R3.1
unnamed: C7.2, R8.1
unnamed: C8.2, R9.1
unnamed: D1.1 (A1), D2.1 (K), D3.1 (K), R1.2
unnamed: C6.1, C8.1, D2.2 (A), D4.1 (K), FB2.2, R3.2
unnamed: C5.1, C7.1, D3.2 (A), D5.1 (K), FB1.2, R2.2
unnamed: C5.2, D6.2 (A2), R10.1, U3.9 (OUT_A)
unnamed: C6.2, D7.2 (A2), R11.1, U3.10 (OUT_B)
unnamed: D8.4 (BK), R23.1
unnamed: D8.3 (GK), R22.1
unnamed: D8.2 (RK), R20.1
unnamed: F1.2, FB1.1
unnamed: F2.2, FB2.1
unnamed: F2.1, J1.1
unnamed: F1.1, J1.2
unnamed: J2.A5 (CC1), R24.1
unnamed: J2.B5 (CC2), R25.1
unnamed: J2.A6 (D+), J2.B6 (D+), U4.27 (GPIO19/USB_D+)
unnamed: J2.A7 (D-), J2.B7 (D-), U4.26 (GPIO18/USB_D-)
unnamed: J2.A4 (VBUS), J2.A9 (VBUS), J2.B4 (VBUS), J2.B9 (VBUS)
unnamed: Q1.3 (D), R14.1, U3.5 (RESET)
unnamed: Q2.3 (D), R15.1, U3.6 (DATA_IN)
unnamed: C9.1, U1.1 (BS)
unnamed: R4.2, R7.2, U1.3 (FB)
unnamed: C9.2, L2.1, U1.6 (SW)
unnamed: C10.2, R5.1, R6.2, U2.1 (FB)
unnamed: L1.1, U2.4 (SW)
unnamed: C18.1, U3.4 (BST)
unnamed: C18.2, U3.3 (BST)
unnamed: R10.2, U3.14 (COLLECTOR_A)
unnamed: R11.2, U3.12 (COLLECTOR_B)
unnamed: R16.2, U3.1 (DATA_OUT)
unnamed: C12.1, R8.2, U3.16 (IN1)
unnamed: C12.2, R9.2, U3.15 (IN2)
unnamed: R12.2, R13.1, U3.2 (VIN)
unnamed: R20.2, U4.12 (GPIO0/ADC1_CH0/XTAL_32K_P)
unnamed: R23.2, U4.5 (GPIO2/ADC1_CH2)
unnamed: R22.2, U4.6 (GPIO3/ADC1_CH3)
unnamed: R19.2, U4.22 (GPIO8)

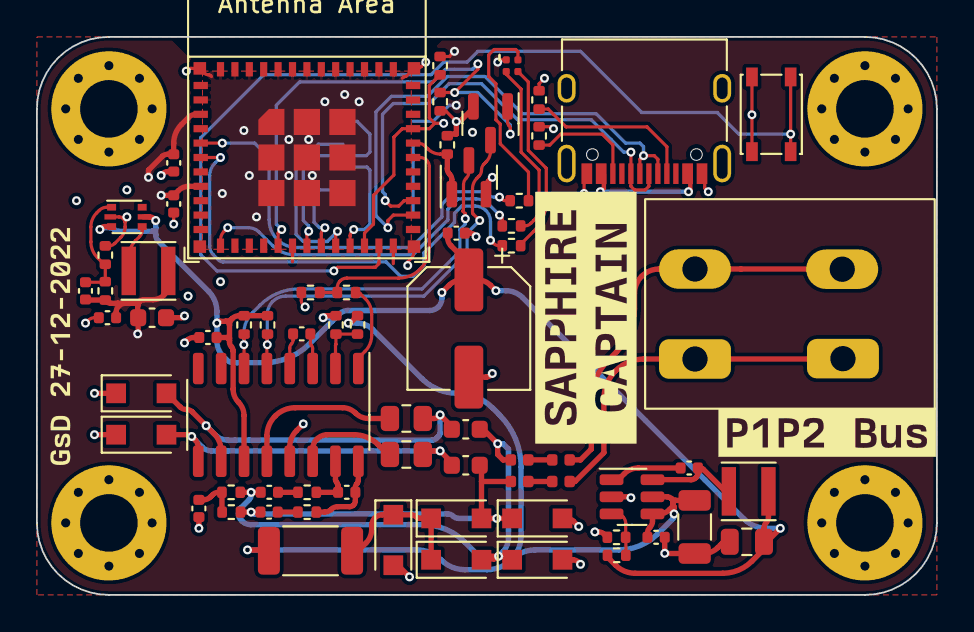
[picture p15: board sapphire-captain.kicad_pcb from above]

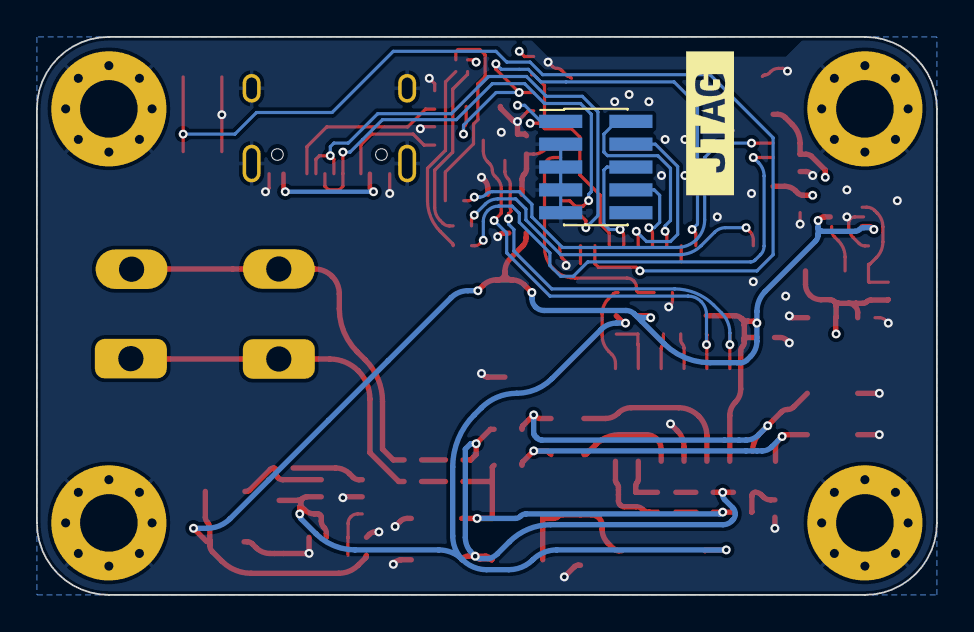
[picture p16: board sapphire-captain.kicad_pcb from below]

Board: 4 copper layers, 50.0 x 31.0 mm, 77 parts (2 on the bottom side), 51 nets.

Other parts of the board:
kibuzzard-63AA5C76: G***; kibuzzard-63AA5C76
kibuzzard-63AA625E: G***; kibuzzard-63AA625E
kibuzzard-63AA640E: G***; kibuzzard-63AA640E
kibuzzard-63AA6405: G***; kibuzzard-63AA6405
kibuzzard-63AA6611: G***; kibuzzard-63AA6611

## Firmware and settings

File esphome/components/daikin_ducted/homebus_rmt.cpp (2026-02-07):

/*
 * SPDX-FileCopyrightText: 2022 Espressif Systems (Shanghai) CO LTD
 *                         2022 Greg Davill
 *
 * SPDX-License-Identifier: Apache-2.0
 */
#include <string.h>
#include "esp_check.h"

#include "homebus_rmt.h"

#include "esphome/core/component.h"
#include "esphome/core/hal.h"
#include "esphome/core/log.h"

namespace esphome
{
  namespace daikin_ducted
  {

    static const char *TAG = "homebus";

    // RMT resolution for homebus, in Hz
    static constexpr uint32_t HOMEBUS_RMT_RESOLUTION_HZ = 4000000UL;

    // Homebus timing parameters (in RMT ticks at HOMEBUS_RMT_RESOLUTION_HZ)
    static constexpr uint32_t HOMEBUS_BIT_RATE = 9600;
    static constexpr uint32_t HOMEBUS_BIT_DURATION = HOMEBUS_RMT_RESOLUTION_HZ / HOMEBUS_BIT_RATE;
    static constexpr uint32_t HOMEBUS_HALF_BIT_DURATION = HOMEBUS_BIT_DURATION / 2;

    // RX buffer size in symbols (enough for 32 bytes * 11 symbols/byte)
    static constexpr size_t RX_BUFFER_SYMBOLS = 32 * 11;

    /*

    Read/Write 1 bit:

              |                BIT_DURATION              | NEXT
              |  HALF_BIT_DURATION  | HALF_BIT_DURATION  | BIT

    ------────────────────────────────────────────────────------




    Read/Write 0 bit:

              |                BIT_DURATION              | NEXT
              |  HALF_BIT_DURATION  | HALF_BIT_DURATION  | BIT

    ------────┐                     ┌─────────────────────------
              │                     │
              │                     │
              │                     │
              └─────────────────────┘

    */

    static void print_packet(const uint8_t *buffer, const uint32_t buffer_length)
    {
      // Each byte needs 3 chars ("xx "), plus prefix (~15) and suffix
      static constexpr size_t MAX_PRINT_BYTES = 48;
      char str[16 + MAX_PRINT_BYTES * 3 + 2];
      char *p = str;

      size_t print_len = (buffer_length > MAX_PRINT_BYTES) ? MAX_PRINT_BYTES : buffer_length;
      p += sprintf(str, "len=%02lu pkt=[", buffer_length);
      for (size_t i = 0; i < print_len; i++)
      {
        p += sprintf(p, "%02x ", buffer[i]);
      }
      if (print_len > 0) {
        *(p - 1) = ']';
      } else {
        *p++ = ']';
      }
      *p = 0;
      ESP_LOGVV(TAG, "%s", str);
    }

    static int homebus_rmt_decode_data(rmt_symbol_word_t *rmt_symbols, size_t symbol_num, uint8_t *decoded_bytes, size_t max_buffer_length)
    {
      size_t byte_pos = 0;

      unsigned int symbol_index = 0;
      while (symbol_index < symbol_num)
      {
        // Sample towards the start of a half bit
        unsigned int accumulator = 0;
        unsigned int sampling_time = HOMEBUS_HALF_BIT_DURATION / 3;
        uint16_t decoded_byte = 0;
        size_t bit_pos = 0;
        while (sampling_time < (HOMEBUS_BIT_DURATION * (11)))
        {
          if (symbol_index > symbol_num)
          {
            ESP_LOGE(TAG, "Invalid symbol index %lu > %lu", symbol_index, symbol_num);
            ESP_LOGE(TAG, "byte_pos = %lu, bit_pos = %lu, accumulator = %lu", byte_pos, bit_pos, accumulator);

            return byte_pos;
          }

          rmt_symbol_word_t *symbol = &rmt_symbols[symbol_index];

          if ((symbol_index <= symbol_num))
          {

            if (symbol->duration0 > (HOMEBUS_BIT_DURATION * (11)))
            {
              ESP_LOGE(TAG, "Invalid symbol duration0: %lu > %lu", symbol->duration0, (HOMEBUS_BIT_DURATION * (11)));
              return byte_pos;
            }
            if (symbol->duration1 > (HOMEBUS_BIT_DURATION * (11)))
            {
              ESP_LOGE(TAG, "Invalid symbol duration1: %lu > %lu", symbol->duration1, (HOMEBUS_BIT_DURATION * (11)));
              return byte_pos;
            }

            accumulator += symbol->duration0;
            while ((sampling_time < accumulator) && (bit_pos < 11))
            {
              sampling_time += HOMEBUS_BIT_DURATION;
              decoded_byte >>= 1;
              bit_pos++;
            }

            accumulator += symbol->duration1;
          }
          // Pad out accumulator if we've timed out
          if ((symbol_index == symbol_num) || (symbol->duration1 == 0))
          {
            accumulator += HOMEBUS_BIT_DURATION * 11;
          }

          while ((sampling_time < accumulator) && (bit_pos < 11))
          {
            sampling_time += HOMEBUS_BIT_DURATION;
            decoded_byte = (decoded_byte >> 1) | (1 << 10);
            bit_pos++;
          }

          symbol_index++;
        }

        /* Check framing and parity */
        if ((decoded_byte & 0x001) == 0x001)
        {
          ESP_LOGE(TAG, "Bad Start framing, %lu (byte:0x%03x, idx=%u, len=%u)", accumulator, decoded_byte, symbol_index, byte_pos);
          print_packet(decoded_bytes, byte_pos);
          return 0;
        }
        if ((decoded_byte & 0x400) != 0x400)
        {
          ESP_LOGE(TAG, "Bad Stop framing, %lu (byte:0x%03x, idx=%u, len=%u)", accumulator, decoded_byte, symbol_index, byte_pos);
          print_packet(decoded_bytes, byte_pos);

          for(int i = 0; i < 18; i++)
            ESP_LOGE(TAG, "  symbol[%u](dur0=%u, dur1=%u)", i, rmt_symbols[i].duration0, rmt_symbols[i].duration1);
          return 0;
        }
        if ((__builtin_popcount(decoded_byte) & 1) == 0)
        {
          ESP_LOGE(TAG, "Bad parity");
          return 0;
        }

        decoded_byte >>= 1;
        decoded_bytes[byte_pos] = decoded_byte;

        if (++byte_pos >= max_buffer_length)
        {
          ESP_LOGE(TAG, "Over max length: %lu > %lu", byte_pos, max_buffer_length);
          return 0;
        }
      }
      return byte_pos;
    }


    // ISR-safe function to restart reception on the current write buffer
    static void IRAM_ATTR start_receive_isr(HomebusStore *store)
    {
      rmt_receive_config_t recv_config = {};
      recv_config.signal_range_min_ns = 1000;
      recv_config.signal_range_max_ns = (HOMEBUS_BIT_DURATION * 12) * 1000000000ULL / HOMEBUS_RMT_RESOLUTION_HZ;

      rmt_receive(store->rx_channel, store->buffers[store->write_idx],
                  store->buffer_size * sizeof(rmt_symbol_word_t), &recv_config);
    }

    static bool IRAM_ATTR rmt_rx_done_callback(rmt_channel_handle_t channel,
                                                const rmt_rx_done_event_data_t *edata,
                                                void *user_data)
    {
      HomebusStore *store = (HomebusStore *)user_data;

      if (edata->num_symbols > 0) {
        if (edata->num_symbols <= store->buffer_size) {
          // Mark current write buffer as ready for reading
          store->read_idx = store->write_idx;
          store->num_symbols = edata->num_symbols;
          // Swap to other buffer for next receive
          store->write_idx ^= 1;
        } else {
          store->overflow = true;
        }
      }

      // Immediately restart reception on the next buffer (ISR-safe in ESP-IDF 5.x)
      start_receive_isr(store);
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

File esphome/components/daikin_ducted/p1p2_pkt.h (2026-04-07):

#pragma once

#include <stdint.h>

namespace esphome
{
namespace daikin_ducted
{

// =============================================================================
// P1P2 Protocol Constants
// =============================================================================

// Packet direction (first byte)
namespace Direction
{
  constexpr uint8_t REQUEST = 0x00;
  constexpr uint8_t RESPONSE = 0x40;
  constexpr uint8_t INIT = 0x80;
}

// Device addresses (second byte)
namespace Address
{
  constexpr uint8_t MAIN_CONTROLLER = 0x00;
  constexpr uint8_t AUX_CONTROLLER = 0xF0;
}

// Packet types (third byte)
namespace PacketType
{
  constexpr uint8_t OPERATING_STATUS = 0x10;
  constexpr uint8_t TEMPERATURES = 0x11;
  constexpr uint8_t POLL_AUX = 0x30;
  constexpr uint8_t UNKNOWN_32 = 0x32;
  constexpr uint8_t OUTDOOR_UNIT_NAME = 0x35;
  constexpr uint8_t INDOOR_UNIT_NAME = 0x36;
  constexpr uint8_t OPERATION_CONTROL = 0x38;
  constexpr uint8_t COUNTER_ALARM = 0x39;
  constexpr uint8_t UNKNOWN_3A = 0x3A;
  constexpr uint8_t UNKNOWN_31 = 0x31;
}

// Operating modes
namespace OperatingMode
{
  constexpr uint8_t FAN_ONLY = 0x60;
  constexpr uint8_t HEAT = 0x61;
  constexpr uint8_t COOL = 0x62;
  constexpr uint8_t AUTO = 0x63;
  constexpr uint8_t DRY = 0x67;
}

// Current action/compressor state
namespace ActionState
{
  constexpr uint8_t IDLE = 0x00;      // Fan running, compressor off
  constexpr uint8_t HEATING = 0x01;
  constexpr uint8_t COOLING = 0x02;
}

// Fan speed values (bits 4-6, masked with 0x70)
namespace FanSpeed
{
  constexpr uint8_t LOW = 0x10;
  constexpr uint8_t MEDIUM = 0x30;
  constexpr uint8_t HIGH = 0x50;
  constexpr uint8_t MASK = 0x70;
  constexpr uint8_t CHANGED_FLAG = 0x80;
}

// Power state
namespace PowerState
{
  constexpr uint8_t OFF = 0x00;
  constexpr uint8_t ON = 0x01;
}

// =============================================================================
// Packet Structures
// =============================================================================

// Generic P1P2 packet header
struct PacketHeader
{
  uint8_t direction;
  uint8_t address;
  uint8_t type;
};

// Packet Type 0x11 - Temperature readings
// Request (direction=0x00): indoor temperature at offset 8-9
// Response (direction=0x40): outdoor intake at 8-9, coolant at 14-15
namespace TemperaturePacket
{
  constexpr size_t INDOOR_TEMP_OFFSET = 8;
  constexpr size_t OUTDOOR_INTAKE_TEMP_OFFSET = 8;
  constexpr size_t COOLANT_TEMP_OFFSET = 14;
}

// Packet Type 0x38 - Operation Control (Request payload offsets)
namespace ControlRequest
{
  constexpr size_t POWER_STATUS = 0;
  constexpr size_t OPERATING_MODE = 2;
  constexpr size_t CURRENT_ACTION = 3;
  constexpr size_t COOLING_SETPOINT = 4;
  constexpr size_t COOLING_FAN_SPEED = 6;
  constexpr size_t HEATING_SETPOINT = 8;
  constexpr size_t HEATING_FAN_SPEED = 10;
  constexpr size_t UNKNOWN_11 = 11;
  constexpr size_t STATUS_FLAGS = 15;
}

// Packet Type 0x38 - Operation Control (Response structure)
struct ControlResponse
{
  uint8_t header[3];           // 0-2: direction, address, type
  uint8_t power_status;        // 3: 0=off, 1=on
  uint8_t operating_mode;      // 4: see OperatingMode
  uint8_t cooling_setpoint;    // 5: target temp for cooling
  uint8_t reserved_6;          // 6: usually 0x00
  uint8_t cooling_fan_speed;   // 7: fan speed + flags
  uint8_t reserved_8;          // 8: usually 0x00
  uint8_t heating_setpoint;    // 9: target temp for heating
  uint8_t reserved_10;         // 10: usually 0x00
  uint8_t heating_fan_speed;   // 11: fan speed + flags
  uint8_t unknown_12;          // 12: copied from request
  uint8_t reserved_13;         // 13: usually 0x00
  uint8_t reserved_14;         // 14: usually 0x00
  uint8_t reserved_15;         // 15: usually 0x00
  uint8_t status_flags;        // 16: 0x20 when power on
  uint8_t reserved_17;         // 17: usually 0x00
  uint8_t reserved_18;         // 18: usually 0x00
  uint8_t reserved_19;         // 19: usually 0x00
  uint8_t crc;                 // 20: CRC byte
};

namespace StatusFlags
{
  constexpr uint8_t POWER_ON = 0x20;
}

// =============================================================================
// Helper Functions
// =============================================================================

// Convert fixed-point temperature (integer + fraction/256) to float
inline float fixed_point_to_float(uint8_t integer, uint8_t fraction)
{
  return static_cast<float>(integer) + (static_cast<float>(fraction) / 256.0f);
}

// Temperature change threshold for publishing state updates
constexpr float TEMP_PUBLISH_THRESHOLD = 0.08f;

// Default target temperature
constexpr uint8_t DEFAULT_TARGET_TEMPERATURE = 25;

// Temperature limits
constexpr float MIN_TEMPERATURE = 18.0f;
constexpr float MAX_TEMPERATURE = 28.0f;
constexpr float TEMPERATURE_STEP = 1.0f;

} // namespace daikin_ducted
} // namespace esphome

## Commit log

2024-04-28 pcb: Update gitignore
2024-04-28 pcb: Add sapphire-captain designs
    pcb: Update sapphire captain
    [sapphire-captain.kicad_pcb, sapphire-captain.kicad_sch]
2024-04-28 pcb: Add sapphire-captain production files
    [sapphire-captain-bom.csv]
2024-04-28 pcb: Add hb-bob designs
    [hb-bob-r0.1.kicad_pcb, hb-bob-r0.1.kicad_sch]
2024-04-28 pcb: Add hb-bob production files
    [BOM-hb-bob-r0p1.csv, hb-bob-r0.1-bom.csv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]
2024-04-28 pcb: Add esp-daikin designs
    [esp-daikin-r1p0.kicad_pcb, esp-daikin-r1p0.kicad_sch]
2024-04-28 pcb: Add esp-daikin production files
2024-04-29 pcb: Update hb-bob
    - Update PN for C10/C11 to support 9600 baud
    - Swap AIO/BIO signals
    - Add pullups to external DIN/RST pins
    [hb-bob-r0.1.kicad_pcb, hb-bob-r0.1.kicad_sch, hb-bob-r1p0.kicad_pcb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]
2024-04-29 pcb: Add hb-bob-r1p0 production files
    [BOM-hb-bob-r1p0.csv, hb-bob-r0.1-bom.csv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]
2024-04-29 pcb: Move esp-daikin folder
    [esp-daikin-r1p0.kicad_pcb, esp-daikin-r1p0.kicad_sch]
2024-04-29 pcb: Update daikin-esp
    - Add test-point for GPIO9
    [esp-daikin-r1p0.kicad_pcb, esp-daikin-r1p0.kicad_sch]
2024-04-29 pcb: Update daikin-esp schematic version
    [esp-daikin-r1p0.kicad_sch]
2024-04-29 pcb: Flip daikin-esp design
    [esp-daikin-r1p0.kicad_pcb]
2024-04-29 pcb: Update kicad library paths
2024-04-29 pcb.esp-daikin: Update PNs
    [esp-daikin-r1p0.kicad_pcb, esp-daikin-r1p0.kicad_sch]
2024-04-29 pcb.esp-daikin: Rename files
    [esp-daikin-r1p1.kicad_pcb, esp-daikin-r1p1.kicad_sch]
2024-10-07 fw: Add template fan control
2024-10-07 pcb.daikin-esp: Add r1p1
    - Add GPIO9 test-point to enter UART boot
    [esp-daikin-r1p1.kicad_pcb, esp-daikin-r1p1.kicad_sch]
2024-10-10 fw: Update template fan from A/C on_state.
2024-10-10 fw: Fix issue where packet may become corrupt
    [homebus_rmt.cpp]
2024-10-13 pcb.daikin-esp: Update production files to r1p1
2025-04-08 mech: Add 3d prints
    [bot_1.0.0.3mf, bot_1.1.0.stl, top_1.0.0.3mf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]
2026-01-31 fix(pcb): fix C3 part number
    fixes #3
    [esp-daikin-r1p1.kicad_pcb, esp-daikin-r1p1.kicad_sch]
2026-02-07 fw: Remove ducted fan template
2026-02-07 fw: Add extra temperature sensors
2026-02-07 feat: Add extra seperate AC/FAN interfaces for homekit
2026-02-07 fix: ensure temperature is syncronised with homebus interface
2026-02-07 feat: add filter status
2026-02-10 fix: Ignore strapping pin warning on TX GPIO
    https://esphome.io/guides/faq/#why-am-i-getting-a-warning-about-strapping-pins
2026-04-07 feat: Acknowledge the 0x31 packet
    - With a remote attached it can go out of sync if the 0x31 is not ACK'd
    fixes gregdavill/daikin-esp#13
    [p1p2_pkt.h]
2026-04-07 fix: Include esp_driver_rmt for ESPHome 2026.3.x compatibility
    ESPHome 2026.3.x excludes esp_driver_rmt by default to speed up builds.
    Re-include it since homebus_rmt uses the ESP-IDF RMT driver directly.
2026-04-19 ci: Use esphome github action and pin to 2026.4.0
    Use the github action whcih runs the build inside a docker container for faster
    builds. Pin to a fixed version for reproducible builds.
    Upload firmware artifact that can be flashed to a device.
